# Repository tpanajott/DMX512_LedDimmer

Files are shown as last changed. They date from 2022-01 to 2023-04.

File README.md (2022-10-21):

# DMX512 Controller with remote LED drivers
This is a wireless DMX512 controller that will accept input of channel data via MQTT, web interface or manual control of a channel via button input. It has built in support for MQTT auto-registration in Home Assistant. The controller can take up to four inputs for buttons that can control 4 channels of DMX data. Each LED Driver board is configured to drive 350mA LEDs and each LED Driver board can be configured for a channel separately.

# Features
* Auto-registration of channels to Home Assistant via MQTT.
* Setup AP to configure parameters to connect to WiFi.
* Web interface to dynamically configured all settings without changing the code.
* Multiple buttons can control the same channel.
* Many settings for controlling dimming behaviour.
* Control of up to 4 different channels of lights.

# Settings
|Setting|Description|
|---|---|
|Device name|Used as WiFi hostname, MQTT client name and as "device name" in Home Assistant.|
|Serial log level|The desired log level for serial output. Simply leave at "Error" or "None" when installed as no serial monitor will be there to capture it.|
|Connect to WiFi|The WiFi SSID (WiFi name) to connect to. Bu pressing the "List"-button a list of all available networks can be shown and a network selected.|
|WiFi Password|The password (PSK) for the chosen WiFi.|
|Minimum button press time|The time, in milliseconds, a button must have the same state before it is considered a press.|
|Time before dimming|The maximum time for a button to be considered a "press". If the button is still held after this amount if time the channel will start dimming.|

## Channel Settings
|Setting|Description|
|---|---|
|Slider|The slider can be used to control brightness directly from the web interface.|
|Enabled|Wether the channel is in use or not.|
|Name|This is used as the light name in Home Assistant.|
|Channel|The DMX channel to send data on. This must match the "slave" card that is connected to the actual LEDs.|
|Minimum Level|Many LEDs simply don't light below to low a voltage. This setting will force at least the light level as the minimum. By using the slider for the channel and noting the value in "Current Output" this value can be found quiet easily.|
|Maximum Level|The maximum light level.|
|Dimming Speed|The time, in milliseconds, between each step up/down when dimming via a button input.|
|Auto-Dimming Speed|The time, in milliseconds, between each step up/down when dimming via web interface or MQTT.|
|Hold Period|The time, in milliseconds, to wait at min/max positions before switching direction and dimming again.|

## Button Settings
|Setting|Description|
|---|---|
|Enabled|Used to enabling checking of button input.|
|Channel|This must match a configured channel in the "DMX Channels"-section. This is the DMX-channel to control.|

## MQTT Settings
|Setting|Description|
|---|---|
|MQTT Server|The address to the MQTT server to be used.|
|MQTT Port|The port of the MQTT server.|
|MQTT Base Topic|The configured MQTT topic for Home Assistant to listen on. The default in Home Assistant is "homeassistant/".|
|Used MQTT authenticaion?|Check if using username and password for authentication to MQTT server.|
|MQTT Username|The username to use for login at the MQTT server.|
|MQTT Password|The password to use for login at the MQTT server.|

## Images
### Web Interface
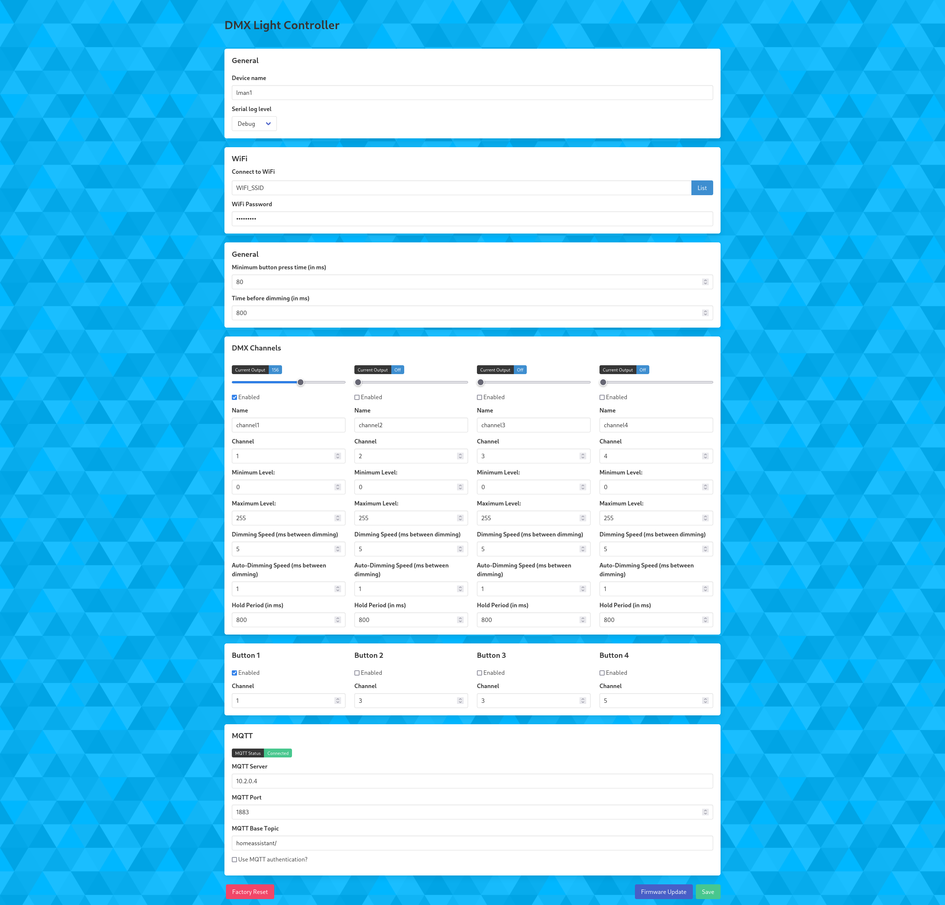
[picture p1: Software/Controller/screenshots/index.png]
Index

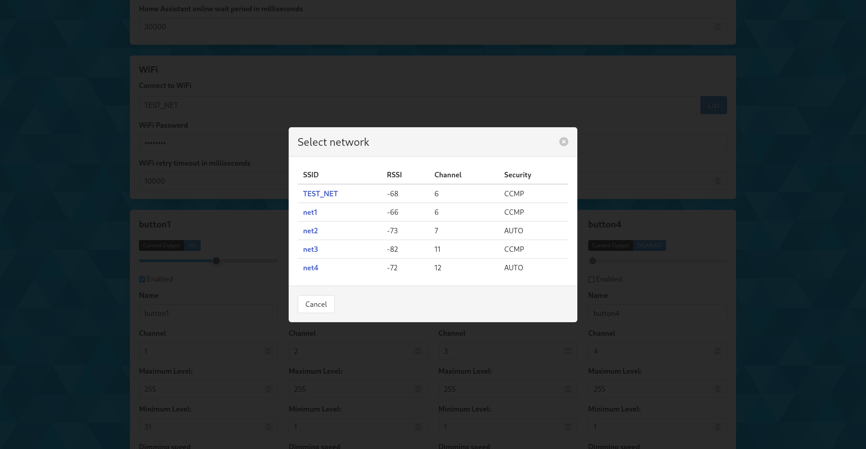
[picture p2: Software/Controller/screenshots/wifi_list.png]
WiFi_list

### Controller board
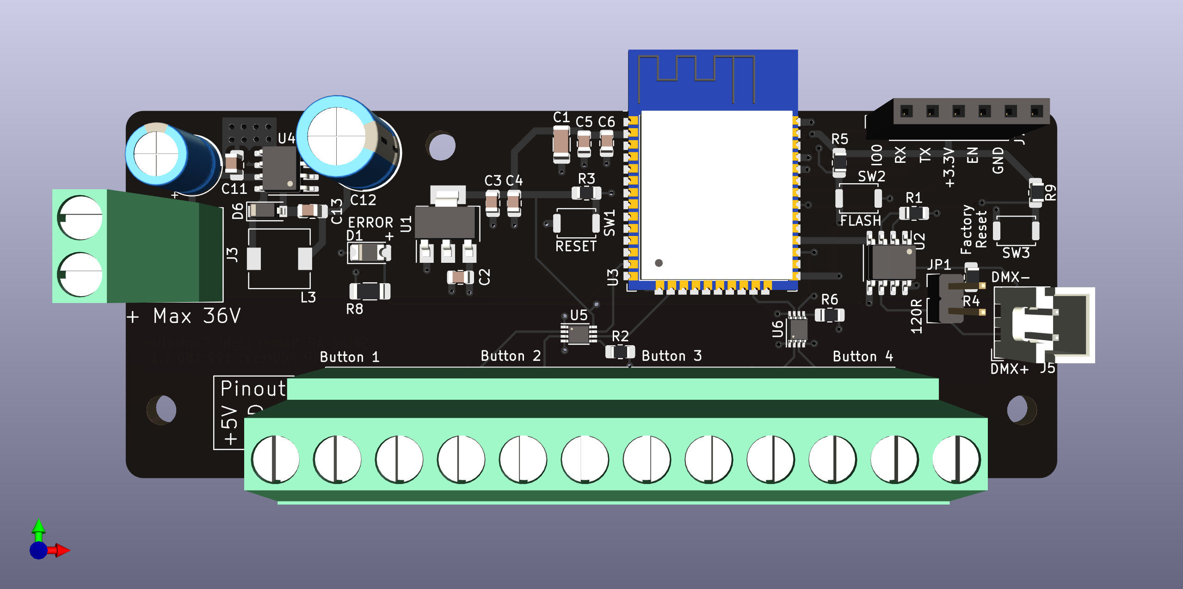
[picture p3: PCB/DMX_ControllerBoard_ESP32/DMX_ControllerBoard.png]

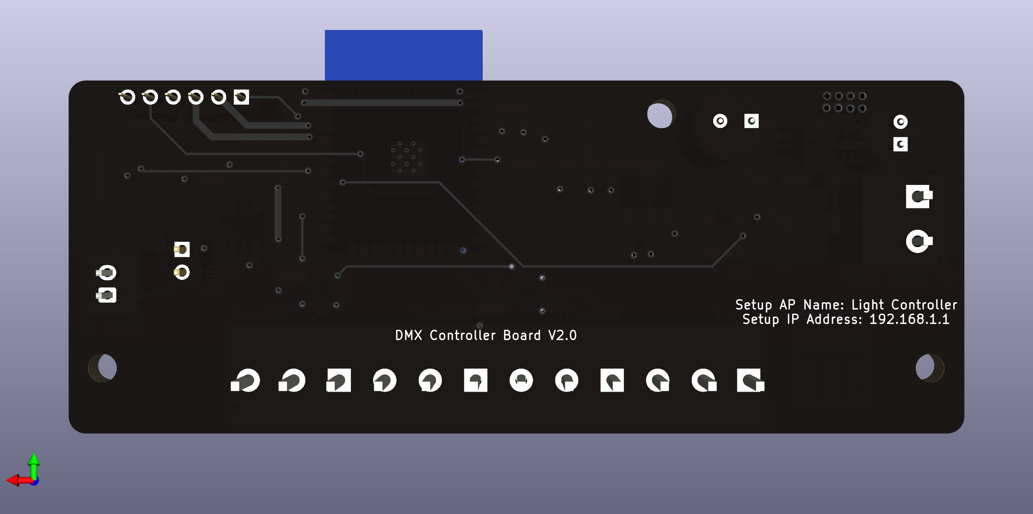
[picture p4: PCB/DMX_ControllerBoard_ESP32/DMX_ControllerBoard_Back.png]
Back

### LED Driver board
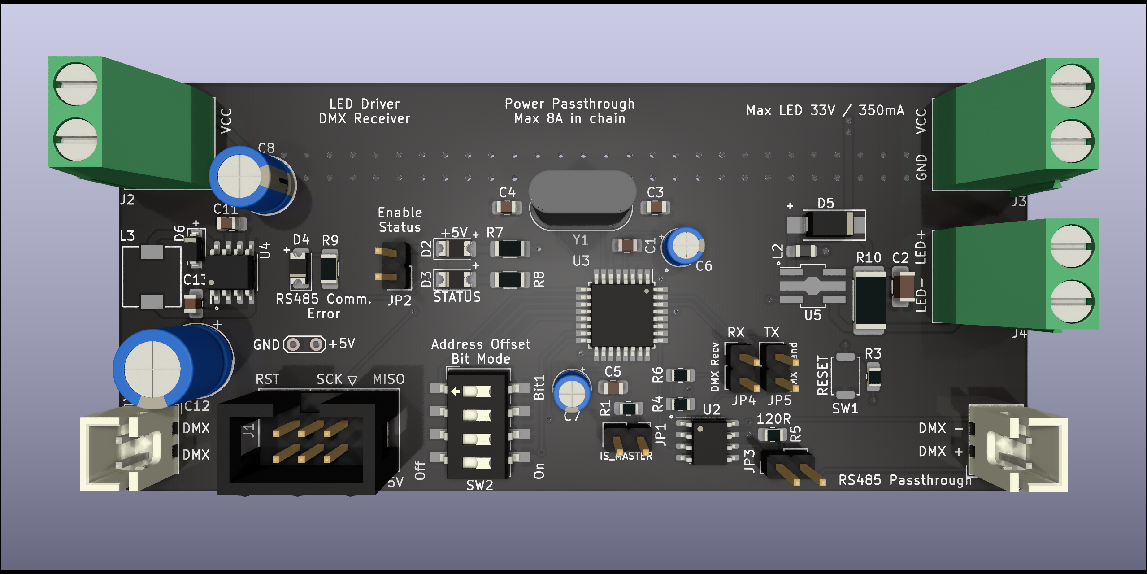
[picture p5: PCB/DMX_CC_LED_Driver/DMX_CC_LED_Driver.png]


## Bugs
* Input for Button 3 does not work. This needs a redesign of the PCB and for it to use an other GPIO input.

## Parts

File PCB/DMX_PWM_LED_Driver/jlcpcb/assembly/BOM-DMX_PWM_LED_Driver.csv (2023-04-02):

Comment | Designator | Footprint | LCSC
Programming_Header | J1 | IDC-Header_2x03_P2.54mm_Vertical | C11214
ATmega328P-AU | U3 | TQFP-32_7x7mm_P0.8mm | C14877
Crystal_Small | Y1 | Crystal_HC49-U_Vertical | C16212
120uF | C12 | CP_Radial_D8.0mm_P3.50mm | C178703
LM2594HVM-5.0 | U4 | SOIC-8_3.9x4.9mm_P1.27mm | C179674
MAX485E | U2 | SOIC-8_3.9x4.9mm_P1.27mm | C19738
L_Small | L3 | L_6.3x6.3_H3 | C206230
TERM_R | JP2,JP3,JP4,JP5 | PinHeader_1x02_P2.54mm_Vertical | C234182
22pF | C3,C4 | C_0805_2012Metric_Pad1.18x1.45mm_HandSolder | C24658
10R | R2 | R_0805_2012Metric | C25278
10K | R1,R3,R4,R6 | R_0805_2012Metric_Pad1.20x1.40mm_HandSolder | C25612
100uF | C8 | CP_Radial_D6.3mm_P2.50mm | C47859
100nF | C1,C11,C13,C5 | C_0805_2012Metric_Pad1.18x1.45mm_HandSolder | C49678
100nF | C2 | C_0805_2012Metric | C519929
SW_DIP_x04 | SW2 | SW_DIP_SPSTx04_Slide_6.7x11.72mm_W8.61mm_P2.54mm_LowProfile | C54950
1uF | C9 | CP_Radial_D5.0mm_P2.00mm | C62934
10uF | C6,C7 | CP_Radial_D4.0mm_P1.50mm | C694328
1N5817 | D6 | D_SOD-123 | C727113
1nF | C10 | C_0603_1608Metric | C77026
MCP1416 | U1 | SOT-23-5 | C83775
PWR_OUT | J2,J3,J4 | TerminalBlock_Phoenix_MKDS-1,5-2_1x02_P5.00mm_Horizontal | C8404
120R | R5 | R_0805_2012Metric_Pad1.20x1.40mm_HandSolder | C966144
SW_SPST | SW1 | SW_Push_SPST_NO_Alps_SKRK
Conn_Right | J6 | JST_XH_B2B-XH-A_1x02_P2.50mm_Vertical
Conn_Left | J5 | JST_XH_B2B-XH-A_1x02_P2.50mm_Vertical
R_LED | R9 | R_1206_3216Metric_Pad1.30x1.75mm_HandSolder
+5V | D2 | D_1206_3216Metric_Pad1.42x1.75mm_HandSolder
WORKING | D3 | D_1206_3216Metric_Pad1.42x1.75mm_HandSolder
R_LED | R7 | R_1206_3216Metric_Pad1.30x1.75mm_HandSolder
R_LED | R8 | R_1206_3216Metric_Pad1.30x1.75mm_HandSolder
RS485_ERROR | D4 | D_1206_3216Metric_Pad1.42x1.75mm_HandSolder
Jump_Gate_Driver | JP1 | SolderJumper-2_P1.3mm_Open_Pad1.0x1.5mm
IRLZ44N | Q1 | TO-220-3_Vertical

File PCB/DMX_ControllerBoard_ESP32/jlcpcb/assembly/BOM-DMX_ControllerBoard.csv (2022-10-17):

Comment | Designator | Footprint | LCSC
100uF/6.3V | C1 | C_1206_3216Metric | C15008
100uF | C12 | CP_Radial_D8.0mm_P3.50mm | C178703
LM2594HVM-5.0 | U4 | SOIC-8_3.9x4.9mm_P1.27mm | C179674
MAX485E | U2 | SOIC-8_3.9x4.9mm_P1.27mm | C19738
L_Small | L3 | L_6.3x6.3_H3 | C206230
CON | JP1 | PinHeader_1x02_P2.54mm_Vertical | C234182
10K | R1,R2,R3,R5,R6,R9 | R_0805_2012Metric_Pad1.20x1.40mm_HandSolder | C25612
AMS1117-3.3 | U1 | SOT-223-3_TabPin2 | C2891839
10uF/25V | C2,C3 | C_0805_2012Metric | C2922480
100uF | C8 | CP_Radial_D6.3mm_P2.50mm | C47859
100nF | C11,C13 | C_0805_2012Metric_Pad1.18x1.45mm_HandSolder | C49678
100nF/16V | C6 | C_0805_2012Metric | C519929
22uF/25V | C4 | C_0805_2012Metric | C602037
Screw_Terminal_01x03 | J1,J2,J4,J6 | TerminalBlock_Phoenix_MKDS-3-3-5.08_1x03_P5.08mm_Horizontal | C72334
1N5817 | D6 | D_SOD-123 | C727113
74LVC2T45DC | U5,U6 | VSSOP-8_2.3x2mm_P0.5mm | C730237
PWR_IN | J3 | TerminalBlock_Phoenix_MKDS-1,5-2_1x02_P5.00mm_Horizontal | C8404
1uF/10V | C5 | C_0805_2012Metric | C92812
120R | R4 | R_0805_2012Metric_Pad1.20x1.40mm_HandSolder | C966144
Conn_Left | J5 | JST_XH_B2B-XH-A_1x02_P2.50mm_Vertical
SW_SPST | SW1 | SW_Push_SPST_NO_Alps_SKRK
ESP32-WROOM-32 | U3 | ESP32-WROOM-32
D_Small | D1 | D_1206_3216Metric_Pad1.42x1.75mm_HandSolder
200R | R8 | R_1206_3216Metric_Pad1.30x1.75mm_HandSolder
SW_SPST | SW2 | SW_Push_SPST_NO_Alps_SKRK
ProgrammingHeader | J7 | PinSocket_1x06_P2.54mm_Vertical
SW_SPST | SW3 | SW_Push_SPST_NO_Alps_SKRK
MountingHole | H1 | MountingHole_3.2mm_M3
MountingHole | H2 | MountingHole_3.2mm_M3
MountingHole | H3 | MountingHole_3.2mm_M3

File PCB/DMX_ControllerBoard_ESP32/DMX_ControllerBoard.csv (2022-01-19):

Reference | Quantity | Value | Footprint | Datasheet | LCSC
C1 C11 C13 | 3 | 100nF | Capacitor_SMD:C_0805_2012Metric_Pad1.18x1.45mm_HandSolder | ~ | C49678
C12 | 1 | 100uF | Capacitor_THT:CP_Radial_D8.0mm_P3.50mm | ~ | C178703
C3 C4 | 2 | 1uF | Capacitor_SMD:C_0805_2012Metric_Pad1.18x1.45mm_HandSolder | ~ | C215803
C8 | 1 | 100uF | Capacitor_THT:CP_Radial_D6.3mm_P2.50mm | ~ | C47859
D1 | 1 | D_Small | Diode_SMD:D_1206_3216Metric_Pad1.42x1.75mm_HandSolder | ~
D6 | 1 | 1N5817 | Diode_SMD:D_SOD-123 | http://www.vishay.com/docs/88525/1n5817.pdf | C727113
H1 H2 H3 | 3 | MountingHole | MountingHole:MountingHole_3.2mm_M3 | ~
J1 J2 J4 J6 | 4 | Screw_Terminal_01x03 | TerminalBlock_Phoenix:TerminalBlock_Phoenix_MKDS-3-3-5.08_1x03_P5.08mm_Horizontal | ~ | C72334
J3 | 1 | PWR_IN | TerminalBlock_Phoenix:TerminalBlock_Phoenix_MKDS-1,5-2_1x02_P5.00mm_Horizontal | ~ | C8404
J5 | 1 | Conn_Left | Connector_JST:JST_XH_B2B-XH-A_1x02_P2.50mm_Vertical | ~
J7 | 1 | ProgrammingHeader | Connector_PinSocket_2.54mm:PinSocket_1x06_P2.54mm_Vertical | ~
JP1 | 1 | CON | Connector_PinHeader_2.54mm:PinHeader_1x02_P2.54mm_Vertical | ~ | C234182
L3 | 1 | L_Small | Inductor_SMD:L_6.3x6.3_H3 | ~ | C206230
R1 | 1 | 10K | Resistor_SMD:R_0805_2012Metric_Pad1.20x1.40mm_HandSolder | ~ | C25612
R2 R3 R5 R7 R9 R10 R11 R12 R13 | 9 | 10k | Resistor_SMD:R_0805_2012Metric_Pad1.20x1.40mm_HandSolder | ~ | C25612
R4 | 1 | 120R | Resistor_SMD:R_0805_2012Metric_Pad1.20x1.40mm_HandSolder | ~ | C966144
R8 | 1 | 200R | Resistor_SMD:R_1206_3216Metric_Pad1.30x1.75mm_HandSolder | ~
SW1 SW2 SW3 | 3 | SW_SPST | Button_Switch_SMD:SW_Push_SPST_NO_Alps_SKRK | ~
TP1 TP2 | 2 | TP_5V | TestPoint:TestPoint_2Pads_Pitch2.54mm_Drill0.8mm | ~
U2 | 1 | MAX485E | Package_SO:SOIC-8_3.9x4.9mm_P1.27mm | https://datasheets.maximintegrated.com/en/ds/MAX1487E-MAX491E.pdf | C19738
U3 | 1 | H7233-1 | Package_TO_SOT_SMD:SOT-89-3_Handsoldering |  | C277849
U4 | 1 | LM2594HVM-5.0 | Package_SO:SOIC-8_3.9x4.9mm_P1.27mm | http://www.ti.com/lit/ds/symlink/lm2594.pdf | C179674
U8 | 1 | ESP-12E | RF_Module:ESP-12E | http://wiki.ai-thinker.com/_media/esp8266/esp8266_series_modules_user_manual_v1.1.pdf | C89297

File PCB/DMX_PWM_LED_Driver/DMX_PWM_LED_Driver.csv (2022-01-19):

Reference | Quantity | Value | Footprint | Datasheet | LCSC
C12 | 1 | 100uF | Capacitor_THT:CP_Radial_D8.0mm_P3.50mm | ~ | C178703
C2 | 1 | 100nF | Capacitor_SMD:C_1206_3216Metric_Pad1.33x1.80mm_HandSolder | ~ | C132170
C3 C4 | 2 | 22pF | Capacitor_SMD:C_0805_2012Metric_Pad1.18x1.45mm_HandSolder | ~ | C24658
C1 C5 C11 C13 | 4 | 100nF | Capacitor_SMD:C_0805_2012Metric_Pad1.18x1.45mm_HandSolder | ~ | C49678
C6 C7 | 2 | 10uF | Capacitor_THT:CP_Radial_D4.0mm_P1.50mm | ~ | C694328
C8 | 1 | 100uF | Capacitor_THT:CP_Radial_D6.3mm_P2.50mm | ~ | C47859
D2 | 1 | +5V | Diode_SMD:D_1206_3216Metric_Pad1.42x1.75mm_HandSolder | ~
D3 | 1 | WORKING | Diode_SMD:D_1206_3216Metric_Pad1.42x1.75mm_HandSolder | ~
D4 | 1 | RS485_ERROR | Diode_SMD:D_1206_3216Metric_Pad1.42x1.75mm_HandSolder | ~
D5 | 1 | DFLS240L-7 | Diode_SMD:D_PowerDI-123 | ~ | C74179
D6 | 1 | 1N5817 | Diode_SMD:D_SOD-123 | http://www.vishay.com/docs/88525/1n5817.pdf | C727113
J1 | 1 | Programming_Header | Connector_IDC:IDC-Header_2x03_P2.54mm_Vertical | ~ | C11214
J2 | 1 | PWR_OUT | TerminalBlock_Phoenix:TerminalBlock_Phoenix_MKDS-1,5-2_1x02_P5.00mm_Horizontal | ~ | C8404
J3 J4 | 2 | PWR_IN | TerminalBlock_Phoenix:TerminalBlock_Phoenix_MKDS-1,5-2_1x02_P5.00mm_Horizontal | ~ | C8404
J5 | 1 | Conn_Left | Connector_JST:JST_PH_S2B-PH-K_1x02_P2.00mm_Horizontal | ~ | C173752
J6 | 1 | Conn_Right | Connector_JST:JST_PH_S2B-PH-K_1x02_P2.00mm_Horizontal | ~ | C173752
JP1 | 1 | TERM_R | Connector_PinHeader_2.00mm:PinHeader_1x02_P2.00mm_Vertical | ~ | C541856
JP2 | 1 | TERM_R | Connector_PinHeader_2.54mm:PinHeader_1x02_P2.54mm_Vertical | ~ | C234182
JP3 JP4 JP5 | 3 | CON | Connector_PinHeader_2.54mm:PinHeader_1x02_P2.54mm_Vertical | ~ | C234182
L2 | 1 | 56uH | Inductor_SMD:L_0805_2012Metric_Pad1.05x1.20mm_HandSolder | ~ | C167496
L3 | 1 | L_Small | Inductor_SMD:L_6.3x6.3_H3 | ~ | C206230
R1 | 1 | 10K | Resistor_SMD:R_0805_2012Metric_Pad1.20x1.40mm_HandSolder | ~ | C25612
R10 | 1 | 0R3 | Resistor_SMD:R_2512_6332Metric_Pad1.40x3.35mm_HandSolder | ~ | C466812
R3 R4 R6 | 3 | 10k | Resistor_SMD:R_0805_2012Metric_Pad1.20x1.40mm_HandSolder | ~ | C25612
R5 | 1 | 120R | Resistor_SMD:R_0805_2012Metric_Pad1.20x1.40mm_HandSolder | ~ | C966144
R7 R8 R9 | 3 | R_LED | Resistor_SMD:R_1206_3216Metric_Pad1.30x1.75mm_HandSolder | ~
SW1 | 1 | SW_SPST | Button_Switch_SMD:SW_Push_SPST_NO_Alps_SKRK | ~
SW2 | 1 | SW_DIP_x04 | Button_Switch_SMD:SW_DIP_SPSTx04_Slide_6.7x11.72mm_W8.61mm_P2.54mm_LowProfile | ~ | C54950
TP1 | 1 | TP_5V | TestPoint:TestPoint_2Pads_Pitch2.54mm_Drill0.8mm | ~
U2 | 1 | MAX485E | Package_SO:SOIC-8_3.9x4.9mm_P1.27mm | https://datasheets.maximintegrated.com/en/ds/MAX1487E-MAX491E.pdf | C19738
U3 | 1 | ATmega328P-AU | Package_QFP:TQFP-32_7x7mm_P0.8mm | http://ww1.microchip.com/downloads/en/DeviceDoc/ATmega328_P%20AVR%20MCU%20with%20picoPower%20Technology%20Data%20Sheet%2040001984A.pdf | C14877
U4 | 1 | LM2594HVM-5.0 | Package_SO:SOIC-8_3.9x4.9mm_P1.27mm | http://www.ti.com/lit/ds/symlink/lm2594.pdf | C179674
U5 | 1 | AP8861 | Package_TO_SOT_SMD:SOT-89-5_Handsoldering | https://datasheet.lcsc.com/lcsc/1806080223_Diodes-Incorporated-AP8801M8G-13_C211408.pdf | C507867
Y1 | 1 | Crystal_Small | Crystal:Crystal_HC49-U_Vertical | ~ | C112572

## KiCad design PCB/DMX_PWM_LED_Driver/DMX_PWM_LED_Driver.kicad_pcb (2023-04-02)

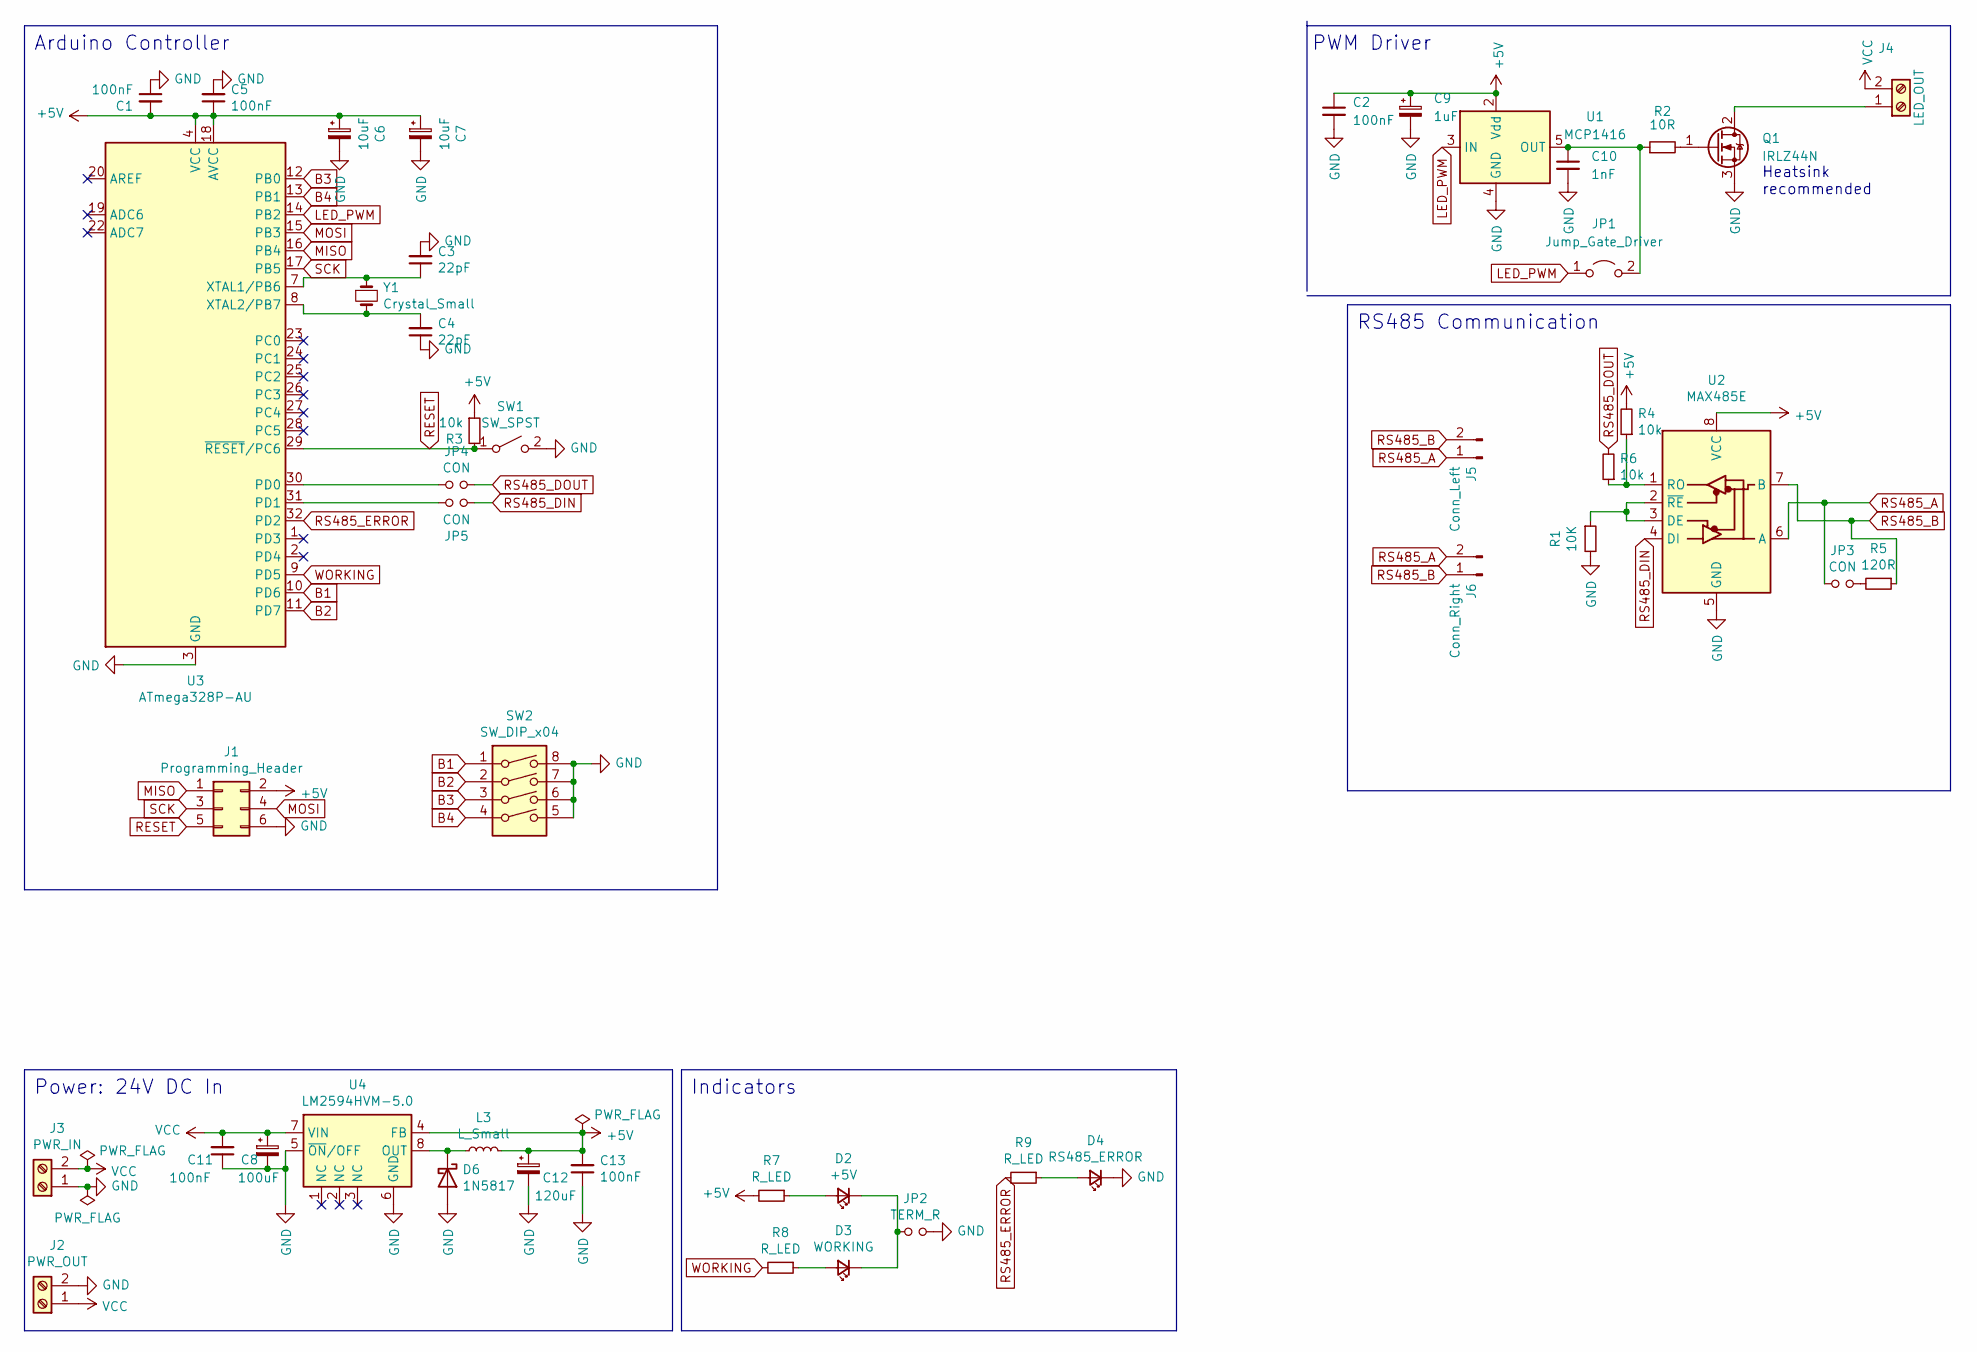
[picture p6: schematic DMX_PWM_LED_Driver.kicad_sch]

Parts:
C1, C5, C11, C13: 100nF; C_0805_2012Metric_Pad1.18x1.45mm_HandSolder; LCSC C49678
C2: 100nF; C_0805_2012Metric; LCSC C519929
C3, C4: 22pF; C_0805_2012Metric_Pad1.18x1.45mm_HandSolder; LCSC C24658
C6, C7: 10uF; CP_Radial_D4.0mm_P1.50mm; LCSC C694328
C8: 100uF; CP_Radial_D6.3mm_P2.50mm; LCSC C47859
C9: 1uF; CP_Radial_D5.0mm_P2.00mm; LCSC C62934
C10: 1nF; C_0603_1608Metric; LCSC C77026
C12: 120uF; CP_Radial_D8.0mm_P3.50mm; LCSC C178703
D2: +5V; D_1206_3216Metric_Pad1.42x1.75mm_HandSolder
D3: WORKING; D_1206_3216Metric_Pad1.42x1.75mm_HandSolder
D4: RS485_ERROR; D_1206_3216Metric_Pad1.42x1.75mm_HandSolder
D6: 1N5817; D_SOD-123; LCSC C727113
J1: Programming_Header; IDC-Header_2x03_P2.54mm_Vertical; LCSC C11214
J2: PWR_OUT; TerminalBlock_Phoenix_MKDS-1,5-2_1x02_P5.00mm_Horizontal; LCSC C8404
J3: PWR_IN; TerminalBlock_Phoenix_MKDS-1,5-2_1x02_P5.00mm_Horizontal; LCSC C8404
J4: LED_OUT; TerminalBlock_Phoenix_MKDS-1,5-2_1x02_P5.00mm_Horizontal; LCSC C8404
J5: Conn_Left; JST_XH_B2B-XH-A_1x02_P2.50mm_Vertical
J6: Conn_Right; JST_XH_B2B-XH-A_1x02_P2.50mm_Vertical
JP1: Jump_Gate_Driver; SolderJumper-2_P1.3mm_Open_Pad1.0x1.5mm
JP2: TERM_R; PinHeader_1x02_P2.54mm_Vertical; LCSC C234182
JP3, JP4, JP5: CON; PinHeader_1x02_P2.54mm_Vertical; LCSC C234182
L3: L_Small; L_6.3x6.3_H3; LCSC C206230
Q1: IRLZ44N; TO-220-3_Vertical
R1: 10K; R_0805_2012Metric_Pad1.20x1.40mm_HandSolder; LCSC C25612
R2: 10R; R_0805_2012Metric; LCSC C25278
R3, R4, R6: 10k; R_0805_2012Metric_Pad1.20x1.40mm_HandSolder; LCSC C25612
R5: 120R; R_0805_2012Metric_Pad1.20x1.40mm_HandSolder; LCSC C966144
R7, R8, R9: R_LED; R_1206_3216Metric_Pad1.30x1.75mm_HandSolder
SW1: SW_SPST; SW_Push_SPST_NO_Alps_SKRK
SW2: SW_DIP_x04; SW_DIP_SPSTx04_Slide_6.7x11.72mm_W8.61mm_P2.54mm_LowProfile; LCSC C54950
U1: MCP1416; SOT-23-5; LCSC C83775
U2: MAX485E; SOIC-8_3.9x4.9mm_P1.27mm; LCSC C19738
U3: ATmega328P-AU; TQFP-32_7x7mm_P0.8mm; LCSC C14877
U4: LM2594HVM-5.0; SOIC-8_3.9x4.9mm_P1.27mm; LCSC C179674
Y1: Crystal_Small; Crystal_HC49-U_Vertical; LCSC C16212

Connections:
+5V: C1.2, C2.1, C5.1, C6.1, C7.1, C9.1, C12.1, C13.2, J1.2, L3.2, R3.1, R4.2, R7.2, U1.2 (Vdd), U2.8 (VCC), U3.4 (VCC), U3.6 (VCC), U3.18 (AVCC), U4.4 (FB)
B1: SW2.1, U3.10 (PD6)
B2: SW2.2, U3.11 (PD7)
B3: SW2.3, U3.12 (PB0)
B4: SW2.4, U3.13 (PB1)
GND: C1.1, C2.2, C3.2, C4.1, C5.2, C6.2, C7.2, C8.2, C9.2, C10.2, C11.1, C12.2, C13.1, D4.1 (K), D6.2 (A), J1.6, J2.2, J3.1, JP2.2, Q1.3 (S), R1.2, SW1.2 (B), SW2.5, SW2.6, SW2.7, SW2.8, U1.4 (GND), U2.5 (GND), U3.3 (GND), U3.5 (GND), U3.21 (GND), U4.5 (~ON/OFF), U4.6 (GND)
LED_PWM: JP1.1 (A), U1.3 (IN), U3.14 (PB2)
MISO: J1.1, U3.16 (PB4)
MOSI: J1.4, U3.15 (PB3)
unnamed: C3.1, U3.7 (XTAL1/PB6), Y1.1
unnamed: C4.2, U3.8 (XTAL2/PB7), Y1.2
unnamed: C10.1, JP1.2 (B), R2.1, U1.5 (OUT)
unnamed: D2.1 (K), D3.1 (K), JP2.1
unnamed: D2.2 (A), R7.1
unnamed: D3.2 (A), R8.1
unnamed: D4.2 (A), R9.1
unnamed: D6.1 (K), L3.1, U4.8 (OUT)
unnamed: J4.1, Q1.2 (D)
unnamed: JP3.2, R5.2
unnamed: JP4.1, U3.30 (PD0)
unnamed: JP5.2, U3.31 (PD1)
unnamed: Q1.1 (G), R2.2
unnamed: R1.1, U2.2 (~RE), U2.3 (DE)
unnamed: R4.1, R6.1, U2.1 (RO)
RESET: J1.5, R3.2, SW1.1 (A), U3.29 (~RESET/PC6)
RS485_A: J5.1, J6.2, JP3.1, U2.6 (A)
RS485_B: J5.2, J6.1, R5.1, U2.7 (B)
RS485_DIN: JP5.1, U2.4 (DI)
RS485_DOUT: JP4.2, R6.2
RS485_ERROR: R9.2, U3.32 (PD2)
SCK: J1.3, U3.17 (PB5)
VCC: C8.1, C11.2, J2.1, J3.2, J4.2, U4.7 (VIN)
WORKING: R8.2, U3.9 (PD5)

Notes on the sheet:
RS485 Communication
Arduino Controller
Indicators
Power: 24V DC In
PWM Driver
Heatsink recommended

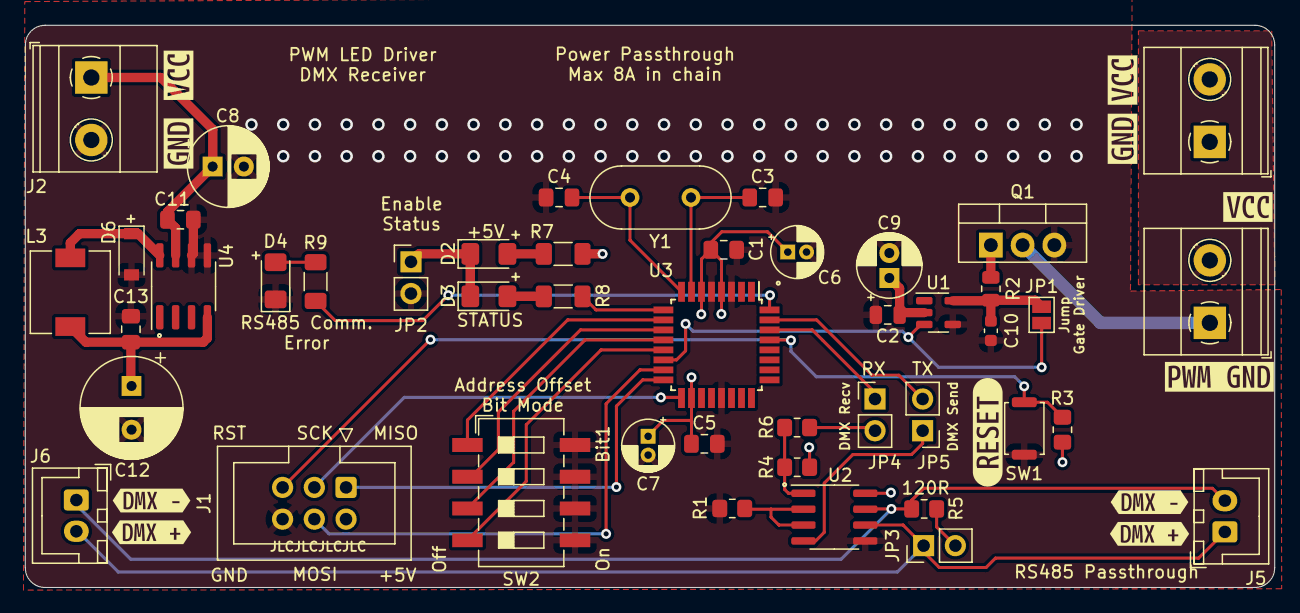
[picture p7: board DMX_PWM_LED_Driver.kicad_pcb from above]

Board: 2 copper layers, 100.0 x 45.0 mm, 57 parts (0 on the bottom side), 33 nets.

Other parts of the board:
kibuzzard-63E822D9: G***; kibuzzard-63E822D9
kibuzzard-63E822E4, kibuzzard-63E822E4#2, kibuzzard-63E822E4#3: G***; kibuzzard-63E822E4
kibuzzard-63E8231D, kibuzzard-63E8231D#2: G***; kibuzzard-63E8231D
kibuzzard-63E8236A, kibuzzard-63E8236A#2: G***; kibuzzard-63E8236A
kibuzzard-63E8237A, kibuzzard-63E8237A#2: G***; kibuzzard-63E8237A
kibuzzard-63E8252B: G***; kibuzzard-63E8252B

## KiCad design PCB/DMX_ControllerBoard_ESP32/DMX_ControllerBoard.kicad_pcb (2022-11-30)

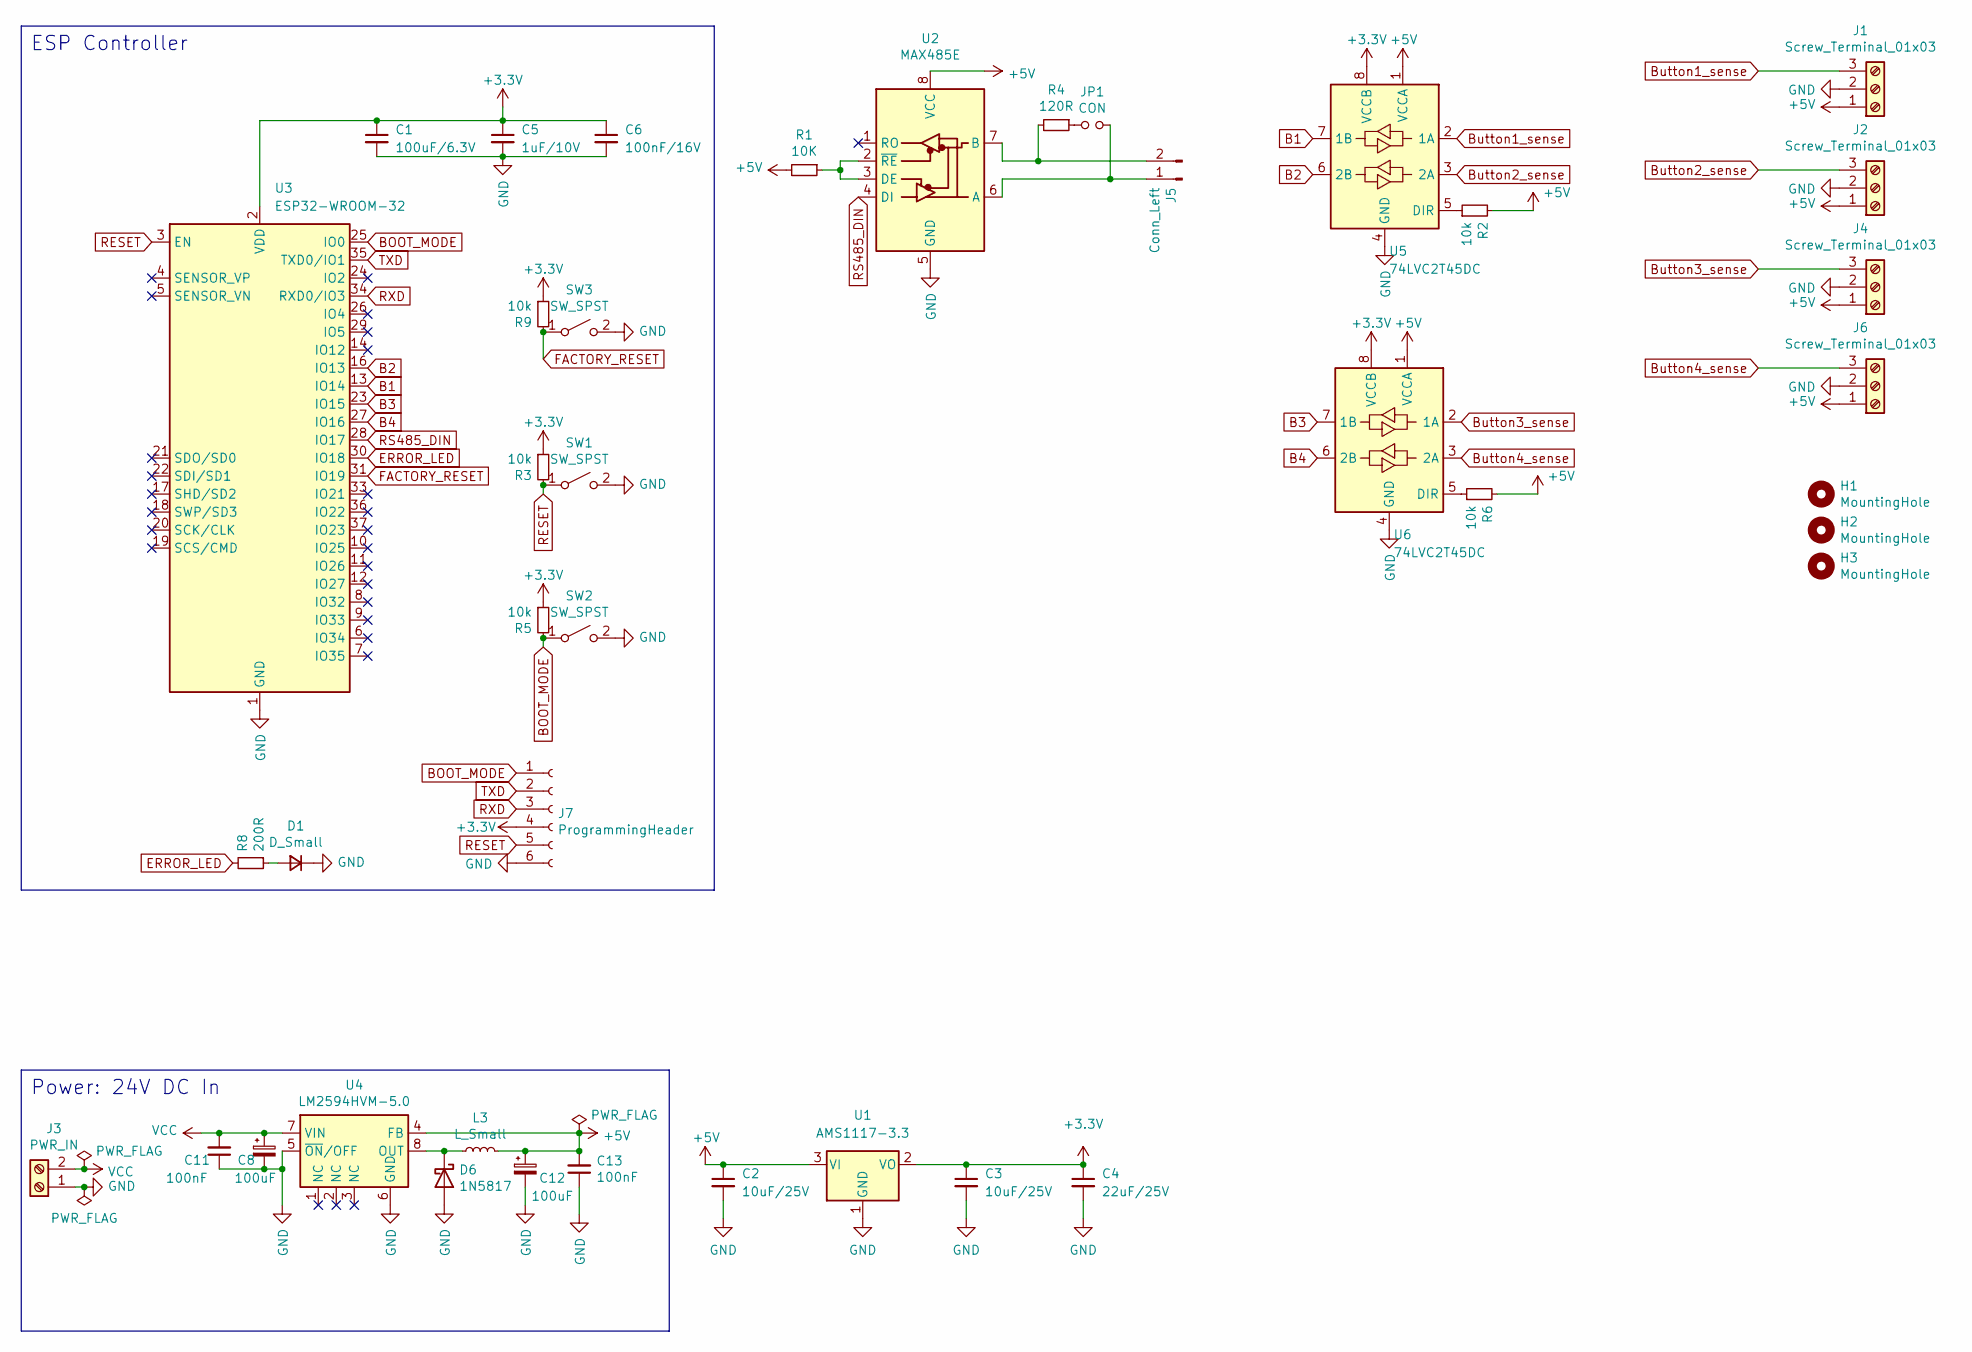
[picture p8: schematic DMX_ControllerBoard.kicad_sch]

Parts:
C1: 100uF/6.3V; C_1206_3216Metric; LCSC C15008
C2, C3: 10uF/25V; C_0805_2012Metric; LCSC C2922480
C4: 22uF/25V; C_0805_2012Metric; LCSC C602037
C5: 1uF/10V; C_0805_2012Metric; LCSC C92812
C6: 100nF/16V; C_0805_2012Metric; LCSC C519929
C8: 100uF; CP_Radial_D6.3mm_P2.50mm; LCSC C47859
C11, C13: 100nF; C_0805_2012Metric_Pad1.18x1.45mm_HandSolder; LCSC C49678
C12: 100uF; CP_Radial_D8.0mm_P3.50mm; LCSC C178703
D1: D_Small; D_1206_3216Metric_Pad1.42x1.75mm_HandSolder
D6: 1N5817; D_SOD-123; LCSC C727113
H1, H2, H3: MountingHole; MountingHole_3.2mm_M3
J1, J2, J4, J6: Screw_Terminal_01x03; TerminalBlock_Phoenix_MKDS-3-3-5.08_1x03_P5.08mm_Horizontal; LCSC C72334
J3: PWR_IN; TerminalBlock_Phoenix_MKDS-1,5-2_1x02_P5.00mm_Horizontal; LCSC C8404
J5: Conn_Left; JST_XH_B2B-XH-A_1x02_P2.50mm_Vertical
J7: ProgrammingHeader; PinSocket_1x06_P2.54mm_Vertical
JP1: CON; PinHeader_1x02_P2.54mm_Vertical; LCSC C234182
L3: L_Small; L_6.3x6.3_H3; LCSC C206230
R1: 10K; R_0805_2012Metric_Pad1.20x1.40mm_HandSolder; LCSC C25612
R2, R3, R5, R6, R9: 10k; R_0805_2012Metric_Pad1.20x1.40mm_HandSolder; LCSC C25612
R4: 120R; R_0805_2012Metric_Pad1.20x1.40mm_HandSolder; LCSC C966144
R8: 200R; R_1206_3216Metric_Pad1.30x1.75mm_HandSolder
SW1, SW2, SW3: SW_SPST; SW_Push_SPST_NO_Alps_SKRK
U1: AMS1117-3.3; SOT-223-3_TabPin2; LCSC C2891839
U2: MAX485E; SOIC-8_3.9x4.9mm_P1.27mm; LCSC C19738
U3: ESP32-WROOM-32
U4: LM2594HVM-5.0; SOIC-8_3.9x4.9mm_P1.27mm; LCSC C179674
U5, U6: 74LVC2T45DC; VSSOP-8_2.3x2mm_P0.5mm; LCSC C730237

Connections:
+3.3V: C1.1, C3.1, C4.1, C5.1, C6.1, J7.4, R3.1, R5.1, R9.1, U1.2 (VO), U3.2 (VDD), U5.8 (VCCB), U6.8 (VCCB)
+5V: C2.1, C12.1, C13.2, J1.1, J2.1, J4.1, J6.1, L3.2, R1.2, R2.2, R6.2, U1.3 (VI), U2.8 (VCC), U4.4 (FB), U5.1 (VCCA), U6.1 (VCCA)
B1: U3.13 (IO14), U5.7 (1B)
B2: U3.16 (IO13), U5.6 (2B)
B3: U3.23 (IO15), U6.7 (1B)
B4: U3.27 (IO16), U6.6 (2B)
BOOT_MODE: J7.1, R5.2, SW2.1 (A), U3.25 (IO0)
Button1_sense: J1.3, U5.2 (1A)
Button2_sense: J2.3, U5.3 (2A)
Button3_sense: J4.3, U6.2 (1A)
Button4_sense: J6.3, U6.3 (2A)
ERROR_LED: R8.2, U3.30 (IO18)
FACTORY_RESET: R9.2, SW3.1 (A), U3.31 (IO19)
GND: C1.2, C2.2, C3.2, C4.2, C5.2, C6.2, C8.2, C11.1, C12.2, C13.1, D1.1 (K), D6.2 (A), J1.2, J2.2, J3.1, J4.2, J6.2, J7.6, SW1.2 (B), SW2.2 (B), SW3.2 (B), U1.1 (GND), U2.5 (GND), U3.1 (GND), U3.15 (GND), U3.38 (GND), U3.39 (GND), U4.5 (~ON/OFF), U4.6 (GND), U5.4 (GND), U6.4 (GND)
unnamed: D1.2 (A), R8.1
unnamed: D6.1 (K), L3.1, U4.8 (OUT)
unnamed: J5.1, JP1.2, U2.6 (A)
unnamed: J5.2, R4.2, U2.7 (B)
unnamed: JP1.1, R4.1
unnamed: R1.1, U2.2 (~RE), U2.3 (DE)
unnamed: R2.1, U5.5 (DIR)
unnamed: R6.1, U6.5 (DIR)
RESET: J7.5, R3.2, SW1.1 (A), U3.3 (EN)
RS485_DIN: U2.4 (DI), U3.28 (IO17)
RXD: J7.3, U3.34 (RXD0/IO3)
TXD: J7.2, U3.35 (TXD0/IO1)
VCC: C8.1, C11.2, J3.2, U4.7 (VIN)

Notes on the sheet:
Power: 24V DC In
ESP Controller

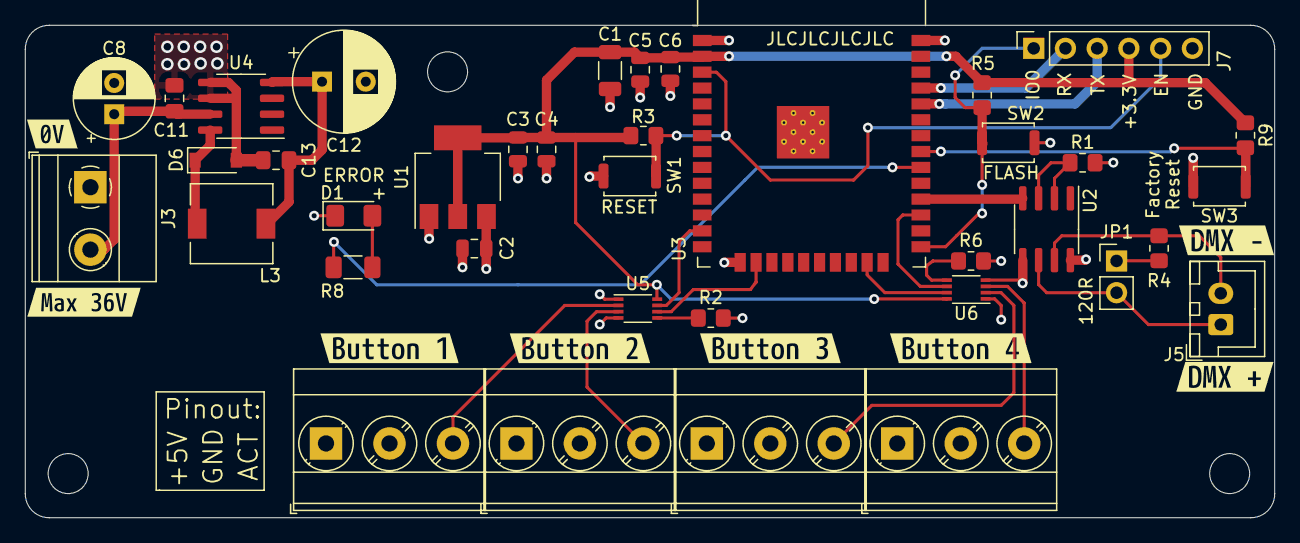
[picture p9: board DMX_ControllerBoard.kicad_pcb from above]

Board: 4 copper layers, 100.0 x 39.4 mm, 49 parts (0 on the bottom side), 27 nets.

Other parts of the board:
kibuzzard-63869B9D: G***; kibuzzard-63869B9D
kibuzzard-63869BC5: G***; kibuzzard-63869BC5
kibuzzard-63869BE0: G***; kibuzzard-63869BE0
kibuzzard-63869BE9: G***; kibuzzard-63869BE9
kibuzzard-638699ED: G***; kibuzzard-638699ED
kibuzzard-6386984B: G***; kibuzzard-6386984B
kibuzzard-63869759: G***; kibuzzard-63869759
kibuzzard-63869791: G***; kibuzzard-63869791

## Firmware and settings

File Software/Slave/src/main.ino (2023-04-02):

#include <Arduino.h>
#include <DMXSerial.h>

// Set DMX receive timeout to 10 seconds by default.
// This value can be trimmed down to start dimming down the lights faster after connection error
// or trimmed up to allow for mor errors on the line before a visual effect is seen
// The receive error led on the PCB will still light up after 500ms
#define DMX_TIMEOUT_MS 10000

#define dimmerPin 9
#define RS485_ERROR_PIN 2
#define STATUS_PIN 5

#define CHANNEL_PIN_B1 6
#define CHANNEL_PIN_B2 7
#define CHANNEL_PIN_B3 8
#define CHANNEL_PIN_B4 9

int dimLevel = 0;
int currentChannel = 0;
float pwm_multiplication_val;
unsigned long lastCurrentChannelRead = 0;
unsigned long lastLightDimmingEvent = 0;

// Set 'TOP' for PWM resolution.  Assumes 16 MHz clock.
// const unsigned int TOP = 0xFFFF; // 16-bit resolution.   244 Hz PWM
// const unsigned int TOP = 0x7FFF; // 15-bit resolution.   488 Hz PWM
// const unsigned int TOP = 0x3FFF; // 14-bit resolution.   976 Hz PWM
// const unsigned int TOP = 0x1FFF; // 13-bit resolution.  1953 Hz PWM
// const unsigned int TOP = 0x0FFF; // 12-bit resolution.  3906 Hz PWM
// const unsigned int TOP = 0x07FF; // 11-bit resolution.  7812 Hz PWM
// const unsigned int TOP = 0x03FF; // 10-bit resolution. 15624 Hz PWM
const unsigned int TOP = 0x01FF; // 9-bit resolution. 31248 Hz PWM

void PWM16Begin()
{
  // Stop Timer/Counter1
  TCCR1A = 0;  // Timer/Counter1 Control Register A
  TCCR1B = 0;  // Timer/Counter1 Control Register B
  TIMSK1 = 0;   // Timer/Counter1 Interrupt Mask Register
  TIFR1 = 0;   // Timer/Counter1 Interrupt Flag Register
  ICR1 = TOP;
  OCR1A = 0;  // Default to 0% PWM
  OCR1B = 0;  // Default to 0% PWM


  // Set clock prescale to 1 for maximum PWM frequency
  TCCR1B |= (1 << CS10);


  // Set to Timer/Counter1 to Waveform Generation Mode 14: Fast PWM with TOP set by ICR1
  TCCR1A |= (1 << WGM11);
  TCCR1B |= (1 << WGM13) | (1 << WGM12);
}


void PWM16EnableA()
{
  // Enable Fast PWM on Pin 9: Set OC1A at BOTTOM and clear OC1A on OCR1A compare
  TCCR1A |= (1 << COM1A1);
  pinMode(9, OUTPUT);
}


void PWM16EnableB()
{
  // Enable Fast PWM on Pin 10: Set OC1B at BOTTOM and clear OC1B on OCR1B compare
  TCCR1A |= (1 << COM1B1);
  pinMode(10, OUTPUT);
}


inline void PWM16A(unsigned int PWMValue)
{
  OCR1A = constrain(PWMValue, 0, TOP);
}


inline void PWM16B(unsigned int PWMValue)
{
  OCR1B = constrain(PWMValue, 0, TOP);
}

void readCurrentChannelSwitches() {
  int channel = 0;

  if(digitalRead(CHANNEL_PIN_B1) == LOW) {
    channel = 1;
  }
  if(digitalRead(CHANNEL_PIN_B2) == LOW) {
    channel = (1 << 1) | channel;
  }
  if(digitalRead(CHANNEL_PIN_B3) == LOW) {
    channel = (1 << 2) | channel;
  }
  if(digitalRead(CHANNEL_PIN_B4) == LOW) {
    channel = (1 << 3) | channel;
  }
  // Add +1 to read the correct register in the DMX library
  currentChannel = channel;
  lastCurrentChannelRead = millis();
}


void setup() {
  DMXSerial.init(DMXReceiver); // Init DMX as receiver
  // Set default values for all channels
  for(int i = 0; i < 15; i++) {
    DMXSerial.write(i + 1, 0);
  }
  pinMode(RS485_ERROR_PIN, OUTPUT);
  pinMode(STATUS_PIN, OUTPUT);
  digitalWrite(STATUS_PIN, HIGH);

  // Setup input with pullup and read channel from DIP-switch
  pinMode(CHANNEL_PIN_B1, INPUT_PULLUP);
  pinMode(CHANNEL_PIN_B2, INPUT_PULLUP);
  pinMode(CHANNEL_PIN_B3, INPUT_PULLUP);
  pinMode(CHANNEL_PIN_B4, INPUT_PULLUP);
  readCurrentChannelSwitches();

  pwm_multiplication_val = sqrt(TOP) / 255;

  // Start PWM
  PWM16B(0);
  PWM16Begin();
  PWM16EnableB();
}

void loop() {
  // Get the currently set channels from the DIP-switches every second.
  if(millis() - lastCurrentChannelRead > 1000) {
    readCurrentChannelSwitches();
  }

  if(currentChannel > 0) {
    // Calculate how long since the last DMX data was received.
    unsigned long lastPacket = DMXSerial.noDataSince();

    // If the last packet we received was less than the timeout value ago, set the value received
    // otherwise, start dimming down current dimming level every 100ms
    if (lastPacket < DMX_TIMEOUT_MS) {
      // Convert sent value with a curve to the high value corresponding to the bit-mode of the PWM
      //dimLevel = round(pow((DMXSerial.read(currentChannel) * 0.25), 2));  // Convert to 12-bit
      dimLevel = round(pow((DMXSerial.read(currentChannel) * pwm_multiplication_val), 2));  // Convert to 10-bit
    } else if (dimLevel > 0) {
      if(millis() - lastLightDimmingEvent > 100) {
        dimLevel--;
        lastLightDimmingEvent = millis();
      }
    }
    PWM16B(dimLevel);

    if(lastPacket > 2000) {
      digitalWrite(RS485_ERROR_PIN, HIGH);
    } else {
      digitalWrite(RS485_ERROR_PIN, LOW);
    }

    // Blink the status LED to show that it is running (this can be disabled by not bridging the jumper)
    digitalWrite(STATUS_PIN, (millis() / 1000) % 2 == 0 ? HIGH : LOW);
  } else {
    // Show an error as no channel has been set.
    digitalWrite(STATUS_PIN, HIGH);

    // Dim light up and down until a channel is selected.
    for(dimLevel = 0; dimLevel < TOP && currentChannel == 0; dimLevel++) {
      readCurrentChannelSwitches();
      PWM16B(dimLevel);
      // Blink RS485-error led fast to show that no channel has been set.
      digitalWrite(RS485_ERROR_PIN, (millis() / 100) % 2 == 0 ? HIGH : LOW);
      delay(20);
    }

    for(dimLevel = TOP; dimLevel > 0 && currentChannel == 0; dimLevel--) {
      readCurrentChannelSwitches();
      PWM16B(dimLevel);
      // Blink RS485-error led fast to show that no channel has been set.
      digitalWrite(RS485_ERROR_PIN, (millis() / 100) % 2 == 0 ? HIGH : LOW);
      delay(20);
    }
  }
}

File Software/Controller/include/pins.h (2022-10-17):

#define PIN_ERROR_LED 18

#define PIN_BUTTON_1 14
#define PIN_BUTTON_2 13
#define PIN_BUTTON_3 15
#define PIN_BUTTON_4 16

#define PIN_DMX_DATA 17

#define PIN_FACTORY_RESET 19

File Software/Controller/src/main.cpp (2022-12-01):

#include <ArduLog.h>
#include <Arduino.h>
#include <string>
#include <LightManager.h>
#include <pins.h>
#include <LMANConfig.h>
#include <ESPDMX.h>
#include <WiFi.h>
#include <PubSubClient.h>
#include <WebManager.h>
#include <version.h>

ArduLog logger;
LMANConfig config;
LightManager lMan;
DMXESPSerial dmx;
TaskHandle_t taskHandleErrorLedHandle = NULL;
TaskHandle_t taskHandleSendDMXData = NULL;
WiFiClient espClient;
PubSubClient mqttClient(espClient);
WebManager webMan;
bool lastResetButtonState = false;
bool homeassistantStatus = true;
unsigned long lastHomeAssistantStateChange = 0;
bool homeAssistantStateChangeHandled = true;
unsigned long lastResetButtonStateChange = 0;

void taskHandleErrorLed(void *param)
{
  LOG_INFO("taskHandleErrorLed started!");
  for (;;)
  {
    if (lastResetButtonState && millis() - lastResetButtonStateChange > 1000)
    {
      digitalWrite(PIN_ERROR_LED, (millis() / 100) % 2 == 0);
    }
    else if (LMANConfig::instance->wifi_ssid.empty())
    {
      digitalWrite(PIN_ERROR_LED, (millis() / 250) % 2 == 0);
    }
    else if (!WiFi.isConnected())
    {
      digitalWrite(PIN_ERROR_LED, 1);
    }
    else if (!mqttClient.connected())
    {
      digitalWrite(PIN_ERROR_LED, (millis() / 500) % 2 == 0);
    }
    else
    {
      // Turn off light if no error exists
      digitalWrite(PIN_ERROR_LED, 0);
    }
    vTaskDelay(100 / portTICK_PERIOD_MS);
  }
}

void mqttCallback(char *topic, byte *payload, unsigned int length)
{
  std::string tpc = topic;
  std::string pld;
  pld.assign((char *)payload, length);
  LOG_TRACE("Got message on ", LOG_BOLD, tpc.c_str());
  LOG_TRACE(pld.c_str());

  std::string homeassistantStatusTopic = LMANConfig::instance->home_assistant_base_topic;
  homeassistantStatusTopic.append("status");

  if (homeassistantStatusTopic.compare(tpc) == 0)
  {
    if (pld.compare("offline") == 0)
    {
      LOG_ERROR("New HA status ", LOG_BOLD, "OFFLINE", LOG_RESET_DECORATIONS, ". Manual control via web interface and physical buttons will still work.");
    }
    else if (pld.compare("online") == 0)
    {
      lastHomeAssistantStateChange = millis();
      homeAssistantStateChangeHandled = false;
      LOG_INFO("New HA status ", LOG_BOLD, "ONLINE");
    }
    else
    {
      LOG_INFO("Got state update for home asssistant, unknown new state: ", LOG_BOLD, pld.c_str());
    }
    return;
  }

  // Message was not a home assistant state update, try to parse as a JSON and state update for light
  StaticJsonDocument<256> doc;
  DeserializationError err = deserializeJson(doc, payload, length);
  if (err)
  {
    LOG_ERROR("Failed to deserialize JSON from message.");
    return;
  }
  // Deserialization was successfull
  for (DMXChannel &channel : LightManager::instance->dmxChannels)
  {
    if (channel.config->channel != 0)
    {
      if (channel.config->getCmdTopic().compare(tpc) == 0)
      {
        try
        {
          LOG_INFO("Got MQTT command for ", LOG_BOLD, channel.config->name.c_str());
          if (doc.containsKey("brightness"))
          {
            uint8_t brightess = 128;
            try
            {
              brightess = doc["brightness"].as<uint8_t>();
            }
            catch (const std::exception &e)
            {
              LOG_ERROR("Failed to cast brightness to uint8_t");
              break; // Error converting. Do not do anything.
            }

            if (channel.state)
            {
              // Light is already on, just dim to requested level.
              LightManager::instance->autoDimTo(&channel, brightess);
            }
            else if (!channel.state)
            {
              // Light is off but a level was requested, turn on and dim to target.
              LOG_INFO("Slow turn on requested by MQTT for ", LOG_BOLD, channel.config->name.c_str(), LOG_RESET_DECORATIONS, " to level ", LOG_BOLD, brightess);
              lMan.autoDimOnToLevel(&channel, brightess);
            }
            else
            {
              LOG_ERROR("Unknown brightness!");
            }
          }
          else if (doc.containsKey("state"))
          {
            std::string state = doc["state"] | "";
            if (!channel.state && state.compare("ON") == 0)
            {
              // Light us currently off and it was requsted on without brightess. Turn on to level from before.
              LOG_INFO("Slow turn on requested by MQTT for ", LOG_BOLD, channel.config->name.c_str());
              lMan.autoDimOn(&channel);
            }
            else if (channel.state && state.compare("OFF") == 0)
            {
              // Light is on and a turn off was requested
              lMan.autoDimOff(&channel);
            }
            else
            {
              LOG_ERROR("Unknown state!");
            }
          }
        }
        catch (const std::exception &e)
        {
          LOG_ERROR("Exception when handling MQTT message: ", LOG_BOLD, e.what());
        }
        break;
      }
    }
  }
}

/// @brief Send, if needed, a status update to MQTT
void sendMqttStatusUpdate()
{
  if (!mqttClient.connected())
  {
    return;
  }

  for (DMXChannel &channel : LightManager::instance->dmxChannels)
  {
    if (channel.config->enabled && channel.config->channel != 0 && millis() - channel.lastLevelChange > 100 && channel.mqttSendUpdate)
    {
      StaticJsonDocument<200> doc;
      doc["state"] = channel.state ? "ON" : "OFF";
      doc["brightness"] = channel.level;

      char buffer[256];
      size_t length = serializeJson(doc, buffer);
      if (mqttClient.publish(channel.config->getStateTopic().c_str(), buffer, length))
      {
        channel.mqttSendUpdate = false;
      }
      else
      {
        LOG_ERROR("Failed to send state update for ", LOG_BOLD, channel.config->name.c_str());
      }
    }
  }
}
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

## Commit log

2022-01-19 First commit of PCB design files
    [DMX_CC_LED_Driver.csv, DMX_CC_LED_Driver.kicad_pcb, DMX_CC_LED_Driver.sch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]
2022-01-19 Updated README and added 3D renders of the boards
2022-02-26 Fixed a bug where the SoftAP would start even though a SSID to connect to was configured
    [DMX_CC_LED_Driver.kicad_sch]
2022-08-06 Fixed a few bugs, added DEBUG flag in DimmerButton to be able to easily toggle debug serial print easy and increased the timeout from 5 to 10 seconds on the slave receiver
    [main.cpp, main.ino]
2022-08-06 Fixed a bug where, if a dimming target via MQTT was to set maximum or minimum brightness, when the physical button was pressed it would have to be pressed twice in order for it to reverse the directi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
2022-09-17 Started migration to new interrupt based light manager with tighter integration to other components
    [main.cpp, pins.h]
2022-09-17 Fixed bug where, if button was released on min or max before the holdPerios was over, the next dimming event would cause the light level to be set to min or max
    [main.cpp]
2022-09-17 Updated to send MQTT status update on setting Auto dim target. Also changed to LOG_<LEVEL> logging instead of println and printf
2022-09-18 Transissioned from an array of dimmerButtons that were always populated with 4 buttons (even if only one was enabled) to a list with only the enabled buttons.
2022-10-01 Switched to my own custom logging library
2022-10-01 Fixed a bug where the calculated of number of DMX channels to initialize was one below required number
    [main.cpp]
2022-10-02 Started work on finding power problems with original board and testing a new ESP32 board
    [DMX_ControllerBoard.csv, DMX_ControllerBoard.kicad_pcb, DMX_ControllerBoard.kicad_sch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]
2022-10-02 Added more labeling to ESP32 board
    [DMX_ControllerBoard.kicad_pcb, DMX_ControllerBoard.kicad_sch]
2022-10-10 Initial commit of ESP32 FreeRTOS implementation
2022-10-10 Initial commit of ESP32 based PCB
    [BOM-DMX_ControllerBoard.csv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]
2022-10-10 Will now cancel any auto-dimming when dimming with the button starts
2022-10-15 It is now possible to control light output via web interface. Also included clamping of values to min/max for channel
2022-10-17 Final tests of software on PCB. Everything seems to be working
2022-10-17 Removed old ESP8266-based software and PCB. Will only support ESP32-based board going forward
    [BOM-DMX_ControllerBoard.csv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]
2022-10-21 Fixed a bug where the wrong channel would be set on buttons. Also fixed a bug where a button press was not properly debounced and would make it basically impossible to turn off the light
2022-11-30 Switched from using iterators to using for loops by reference for clarity
2022-11-30 Updated labels on PCB for better readability
    [DMX_ControllerBoard.kicad_pcb]
2022-11-30 Reverted back to polling button states as it seemed more stable Reverted back to not using retained MQTT messages and to instead listen for Home Assistant events and re-register as needed
    [main.cpp]
2022-11-30 Added "reboot" button to start page
2022-12-01 Fixed more vTaskDelays that were missing the "/ portTICK_PERIOD_MS"
    [main.cpp]
2022-12-03 Will skip debounce checking when button goes from confirmed PRESSED to DEPRESSED in order to not dim for a few more milliseconds and therfore not stopping at desiered level
2023-02-11 Started work on PWM LED Driver and fixed small spelling mistakes
    [DMX_CC_LED_Driver.kicad_pcb, DMX_ControllerBoard.kicad_sch, DMX_PWM_LED_Driver.csv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]
2023-04-02 Updated design of PWM board and code updated for slave boards
    [BOM-DMX_PWM_LED_Driver.csv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]
